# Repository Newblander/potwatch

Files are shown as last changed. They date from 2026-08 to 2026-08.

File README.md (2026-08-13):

# PotWatch

**A clip-on kitchen timer that waits for the water to actually boil.**

*"A watched pot never boils" — so let PotWatch watch it.*

[**potwatch.net**](https://potwatch.net) · Open hardware · Free forever · Not patented, not trademarked

<p align="center">
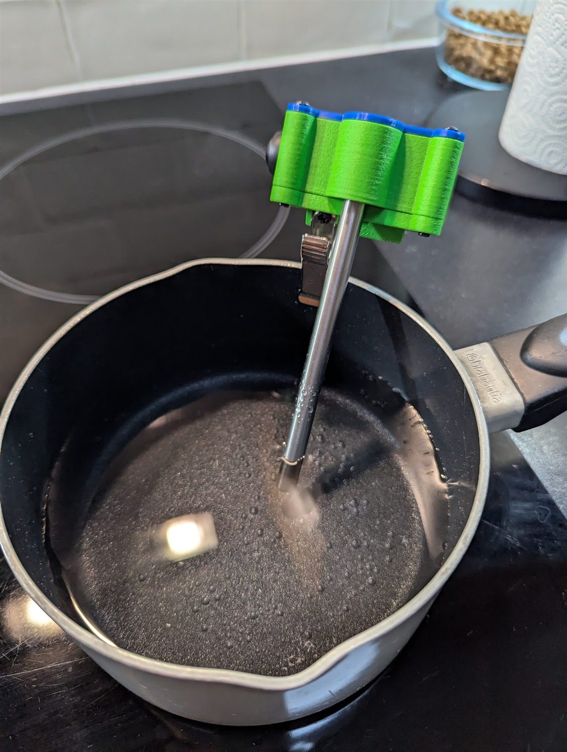
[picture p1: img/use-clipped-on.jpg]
PotWatch clipped to a saucepan with its stainless probe in the water
  
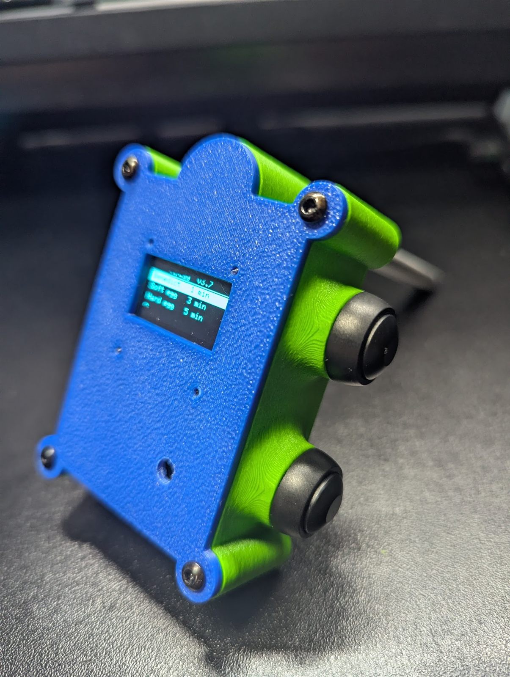
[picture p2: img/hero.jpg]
The PotWatch prototype with its OLED menu lit up
  
</p>

---

Every kitchen timer has the same flaw: it starts counting when you press the button. But "3 minutes for a soft-boiled egg" means three minutes *of boiling*. So you stand at the stove watching for bubbles, guess the moment, and accept that breakfast is a coin flip.

PotWatch hangs on the rim of the pot with a stainless steel probe in the water. It waits until the water reaches the temperature you set, starts the countdown itself, and sounds the alarm when the food is done. Then you can walk away — which is the entire point.

Everything needed to build one is in this repository, and the full documentation is at **[potwatch.net](https://potwatch.net)**.

## It in use

<p align="center">
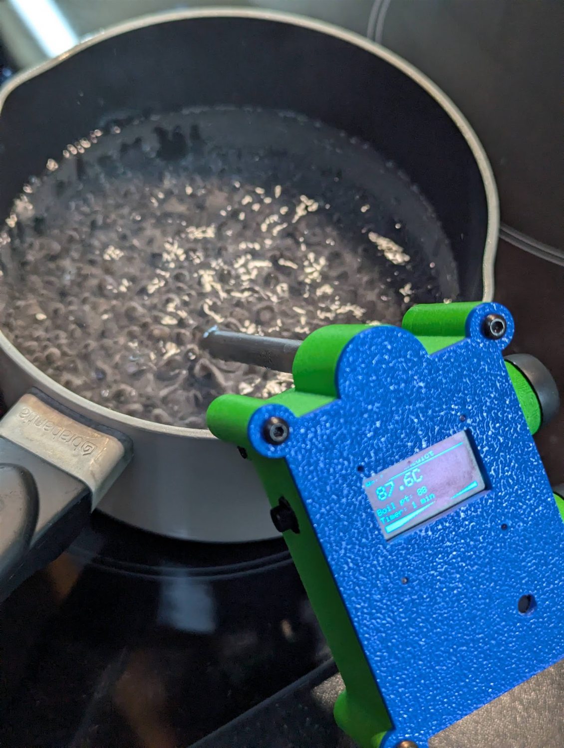
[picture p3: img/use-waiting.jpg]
Screen reading 87.6 C against a trigger of 88
  
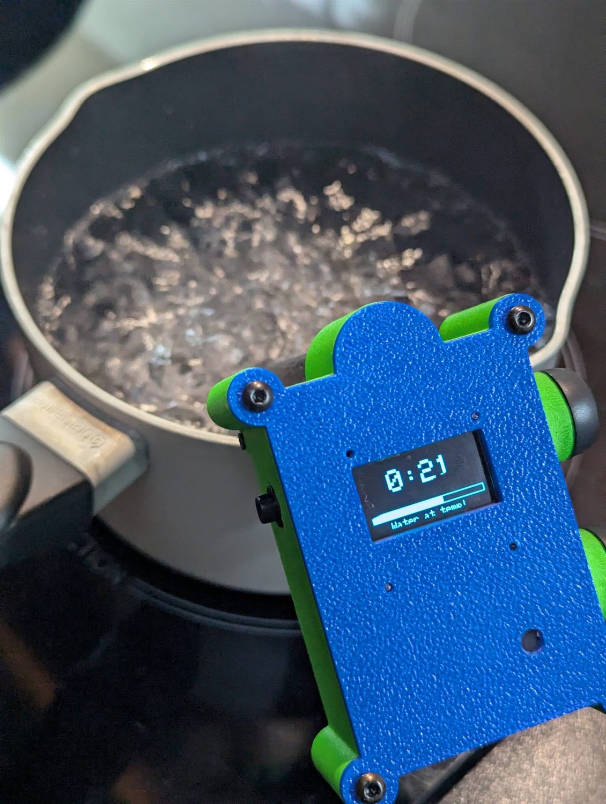
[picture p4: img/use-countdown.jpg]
Counting down from twenty-one seconds, water at temp
  
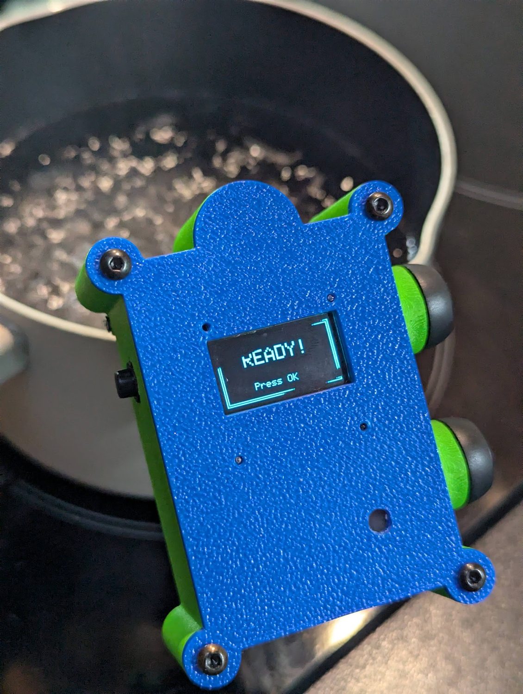
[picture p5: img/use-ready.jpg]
Screen showing READY and Press OK
  
</p>

Left to right: **87.6 °C** against the 88 °C this unit triggers at — the water is working but the countdown has not started. Then the threshold is cleared five times over and the timer runs. Then it shouts.

There is a [12-second clip](video/potwatch-in-use.mp4) of the same thing happening.

## Why the temperature matters

Water does not boil at 100 °C. It boils at whatever the local air pressure dictates — lower at altitude, and drifting by a fraction of a degree as the weather changes. A device that waits for a fixed 100 °C either waits forever or starts early.

PotWatch carries a BMP280 barometer and computes its own threshold:

```
trigger = calibratedTemperature + (currentPressure − calibratedPressure) × 0.03
          clamped to 85…102 °C
```

A one-time calibration pins down the baseline for your kitchen; the barometer handles the daily drift.

**And the threshold does not have to be the boiling point.** What you are really setting is *the temperature at which the countdown starts*. Well before a full boil the water is already working hard — on the author's hob that point is around **88 °C**, which is a fine moment to start timing and turn the heat down. Gentler than a rolling boil, and for most things a better way to cook.

## Features

- **Confirmed detection** — the probe is read every second and five consecutive readings above threshold are required. Steam, splashes and stirring do not trigger it.
- **Pressure compensation** — automatic correction for altitude and weather.
- **Presets** — Benedict (1 min), soft egg (3 min), hard egg (5 min), soup (15 min – 2 h), free-form timer (1 min – 6 h).
- **Dry-pot protection** — if the water boils away and the probe passes 105 °C, the countdown stops and a `NO WATER` alarm sounds.
- **Probe fault detection** — a disconnected or failing sensor shows `CHECK PROBE` rather than inventing a number.
- **Non-blocking alarm** — the buzzer runs from a sequencer, so the buttons stay responsive while it sounds.
- **Self-resetting** — lift the probe out and it silences itself and returns to the menu.
- **Cordless** — LiPo cell, charges over USB-C.

## What is in here

```
├── firmware/potwatch/potwatch.ino   the firmware (Arduino, GPLv3)
├── hardware/
│   ├── wiring-diagram.svg           full schematic, including the power chain
│   └── models/                      the four printed parts, as STL and STEP
├── img/                             photographs
├── video/                           12-second demonstration
├── LICENSE.txt                      GPL v3 — the firmware
└── LICENSE-CC-BY-SA-4.0.txt         CC BY-SA 4.0 — hardware, models, docs
```

## Bill of materials

Roughly **€25** of common hobby parts.

| Part | Notes |
|---|---|
| ESP32-C3 Super Mini | The brain — flashes over USB-C, no programmer needed |
| DS18B20 | Buy the **waterproof probe** version, not the bare chip |
| Stainless steel thermowell | Ready-made, threaded fitting and cable gland; food-grade, cut to length |
| BMP280 barometer | I²C `0x76` — **not** the BME280, which looks identical |
| SSD1306 OLED, 128×64 | I²C `0x3C` |
| Passive piezo buzzer | **Passive**, not active — an active one knows only one note |
| 2 × panel-mount push button | SET and OK — the entire interface |
| 4.7 kΩ resistor | Pull-up for the sensor data line |
| Thermal paste + thin wire | **Do not skip** — see the induction warning below |
| LiPo cell, 3.7 V | 802060 pouch, 1000 mAh on the prototype |
| TP4056 USB-C charger | Get the version **with battery protection** |
| 3.3 V step-down module | Buck converter. A substitute must work from **under 4.2 V** and idle in microamps — **not** LM2596 or MP1584 (both need 4.5 V+), not AMS1117 |
| Self-locking power switch | Breaks the 3.3 V line after the regulator |
| Stainless spring clip | Bought part, screwed between the two printed holders |
| M3 × 6 mm screws ×6, 2 mm self-tappers ×4 | Self-thread into 2.8 mm and 1.8 mm printed holes |

## Wiring

| ESP32-C3 pin | Connects to |
|---|---|
| `GPIO3` | DS18B20 data — needs the 4.7 kΩ pull-up to 3.3 V |
| `GPIO4` | I²C SDA — OLED and BMP280 |
| `GPIO5` | I²C SCL — OLED and BMP280 |
| `GPIO6` | Piezo buzzer, driven directly |
| `GPIO7` | OK button → GND |
| `GPIO10` | SET button → GND |
| `GND` | Also bonded to the stainless thermowell — see below |

Power chain: **cell → TP4056 → 3.3 V step-down → switch → board 3V3 pin.** The board's own USB-C port is for flashing only.

PotWatch wiring diagram

## Printing

| Part | Size | Material on the prototype |
|---|---|---|
| [enclosure](hardware/models/enclosure.stl) · [STEP](hardware/models/enclosure.step) | 60.5 × 84 × 24 mm | Fibre-reinforced ABS |
| [cover](hardware/models/cover.stl) · [STEP](hardware/models/cover.step) | 59 × 84 × 3 mm | ASA |
| [holder1](hardware/models/holder1.stl) · [STEP](hardware/models/holder1.step) | 59 × 15 × 5 mm | Fibre-reinforced ABS |
| [holder2](hardware/models/holder2.stl) · [STEP](hardware/models/holder2.step) | 35 × 15 × 5 mm | Fibre-reinforced ABS |

Every part is published twice: **STL** to print as-is, **STEP** to edit. Bambu Studio, PrusaSlicer and OrcaSlicer import STEP directly, so either one goes straight into the slicer.

Standard slicer settings, no supports needed. **ABS and ASA are chosen deliberately:** the device sits above a pot of steam, and PLA softens around 60 °C. Both want an enclosed printer; on an open-frame machine PETG is the sensible compromise.

The screw holes are printed undersized on purpose so the screws cut their own thread — no nuts and no inserts. Different filaments shrink differently, so test one hole before printing the lot. If you prefer heat-set inserts, open the holes out — that is what the STEP files are for.

## Flashing

1. Install the Arduino IDE and the Espressif ESP32 board package.
2. Install `OneWire`, `DallasTemperature`, `Adafruit GFX`, `Adafruit SSD1306`, `Adafruit BMP280`.
3. Keep `potwatch.ino` in a folder named `potwatch`.
4. Select your ESP32-C3 board. If the serial monitor stays silent, enable **USB CDC On Boot**.
5. Disconnect the battery, connect USB-C and upload.
6. Two beeps means it is alive. Serial at 115200 baud prints live temperatures.

Full instructions: **[potwatch.net/firmware](https://potwatch.net/firmware/)**

## Calibration

Boil a pot, put the probe in, open **Calibrate**, match the right-hand number to the left with SET/OK, hold SET for two seconds. Three beeps confirm it is stored.

Settings live in NVS under the namespace `clipegg` — the project's former name, kept deliberately so calibration survives firmware upgrades.

## ⚠️ If you cook on induction, read this

Early prototypes destroyed DS18B20 sensors one after another. The cause was the hob: a bare semiconductor inside a metal tube next to a large alternating magnetic field. The steel sleeve added to *protect* the sensor was acting as an antenna, feeding the interference straight into it.

Two changes fixed it:

1. **Bed the sensor in thermal paste** (ordinary CPU heatsink compound) before sliding it into the thermowell.
2. **Bond the steel thermowell to GND** with a wire.

The grounded tube becomes a shield rather than an antenna. The paste removes the air gap, which also makes the probe respond noticeably faster.

No failures since, over several months of induction use. That is months of evidence, not years — if you build one and still lose a sensor, please open an issue.

## Known issue — and where help is wanted

**The clip is the weak point.** It holds only when its screws are done up firmly, and the tension slackens with use. Slack enough and the device can tip, lifting the probe out of the liquid — where it will faithfully report that your water is cold and wait forever.

Conveniently, the mount is the most self-contained part of the design: **[`holder1.step`](hardware/models/holder1.step) and [`holder2.step`](hardware/models/holder2.step)** are what carry the spring clip, and nothing else depends on their shape. A better clamp costs you two files, not a rebuild.

If clamping mechanisms are your area, this is the single most valuable contribution the project could receive. Issues and pull requests welcome.

## Licence

- **Firmware** (`firmware/`) — [GNU GPL v3](LICENSE.txt)
- **Hardware, models, diagrams, photographs and documentation** — [CC BY-SA 4.0](LICENSE-CC-BY-SA-4.0.txt)

Nothing here is patented or trademarked, and it never will be.

### How to credit this project

If you publish a remix, a fork, a photo set or a build guide based on the models, diagrams or documentation, copy this line somewhere sensible — a description, a README, a caption:

> PotWatch by Ilia Kuzmin — https://potwatch.net — licensed [CC BY-SA 4.0](https://creativecommons.org/licenses/by-sa/4.0/). Modified from the original.

Drop the last sentence if you did not change anything. That is the whole obligation: **say who made it, link back, note that you changed it, and keep your version under the same licence.**

For the **firmware** the rules are different and a little lighter. GPL v3 does not ask you to advertise anyone. It asks you to keep the copyright notice in the source files, mark what you changed, publish your source under GPL v3 as well, and make that source available to anyone you give a device to. You are free to sell hardware running it.

**What is not covered:** copyright protects these *files*, not the idea. If you look at this thing and design your own from scratch, you owe nothing at all — go ahead, and tell me how it turned out.

---

Made by **Ilia Kuzmin**, 2026 — [3d.ilia.ireland@gmail.com](mailto:3d.ilia.ireland@gmail.com) · [3diy.ie](https://www.3diy.ie/)

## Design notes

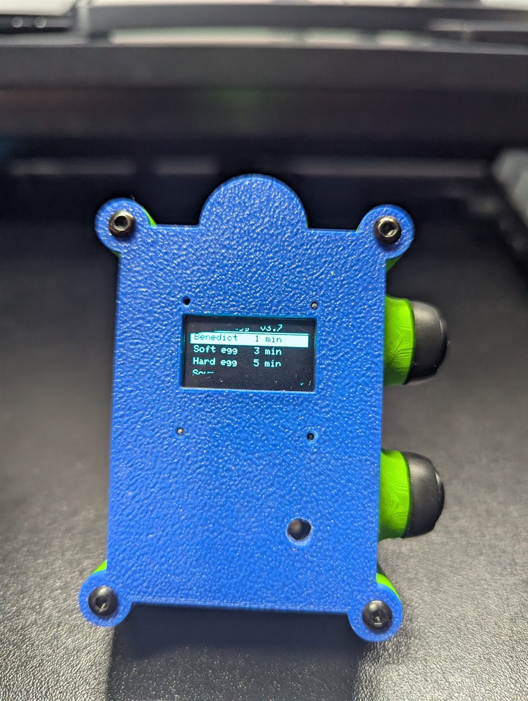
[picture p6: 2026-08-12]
img/menu-front.jpg

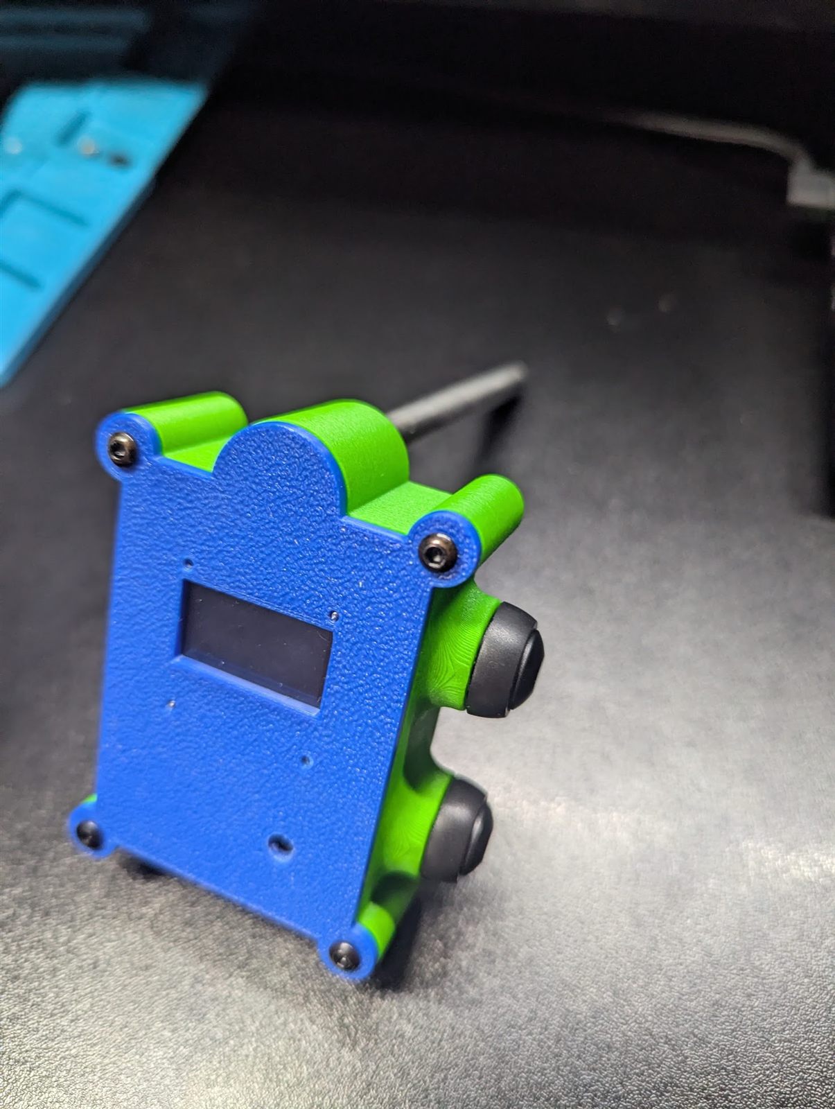
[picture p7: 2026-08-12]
img/device-front.jpg

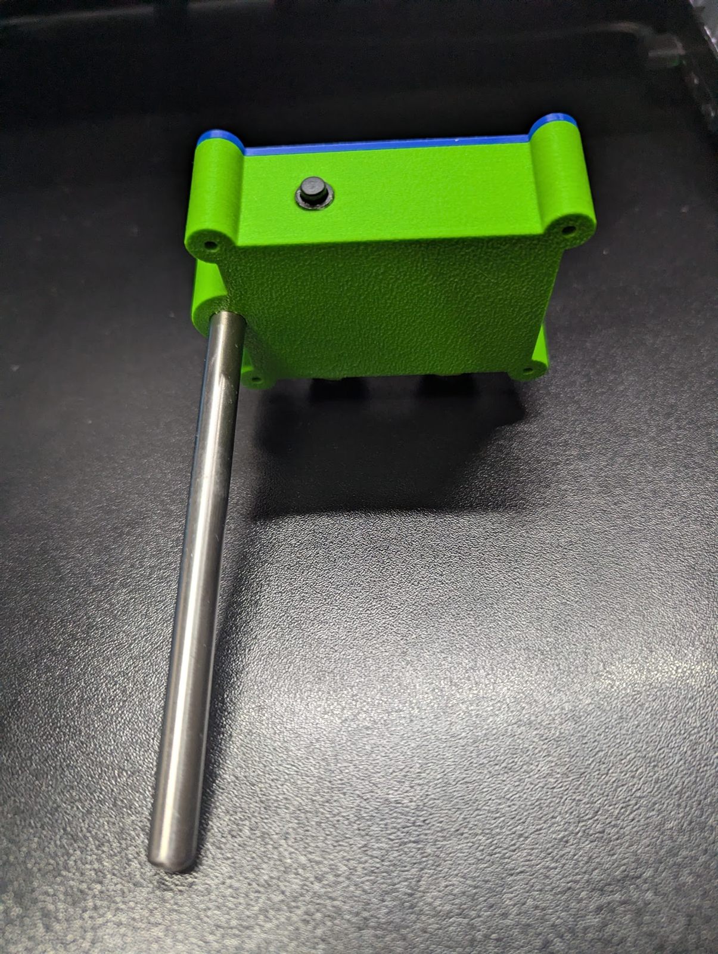
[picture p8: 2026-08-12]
img/probe-back.jpg

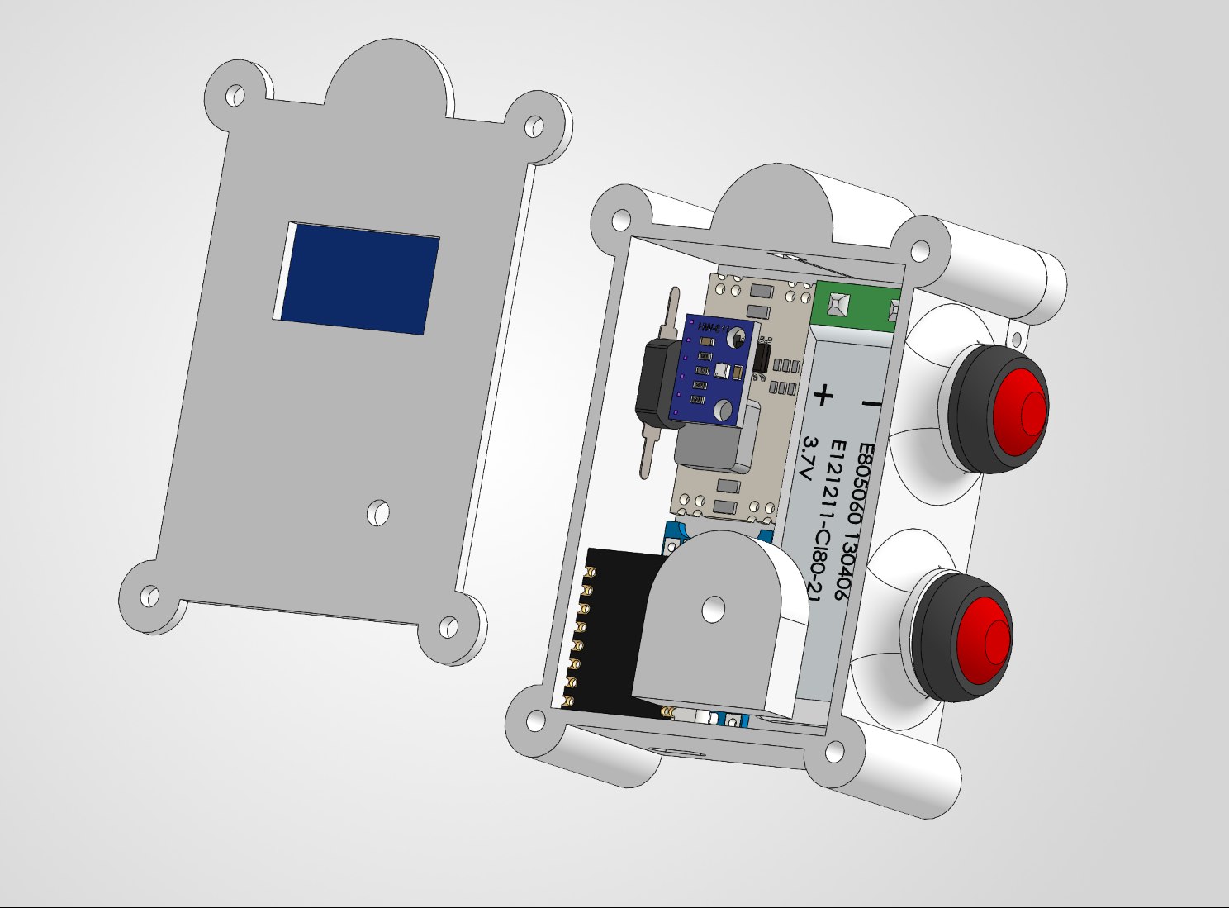
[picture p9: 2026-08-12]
img/exploded-view.jpg

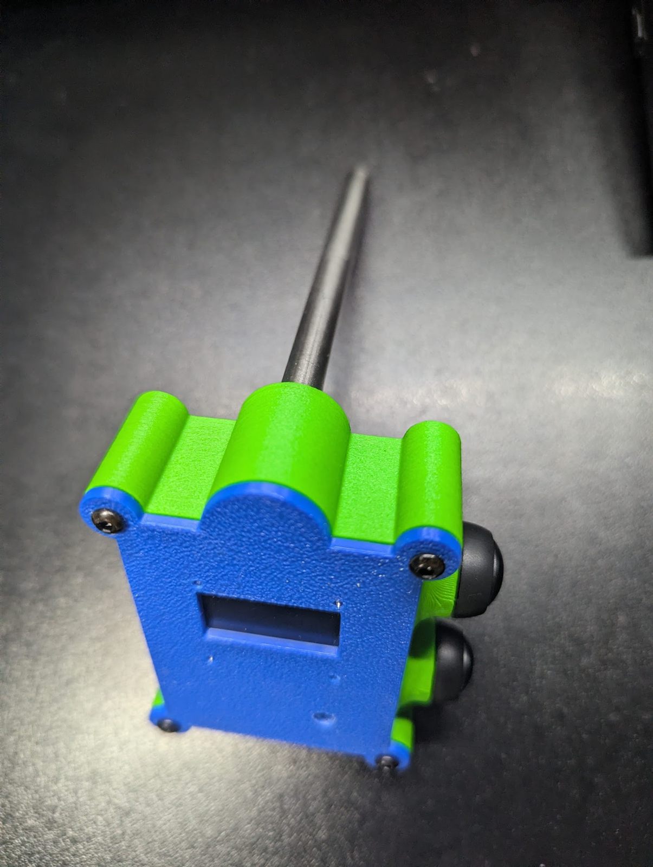
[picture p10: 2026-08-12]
img/top-probe.jpg

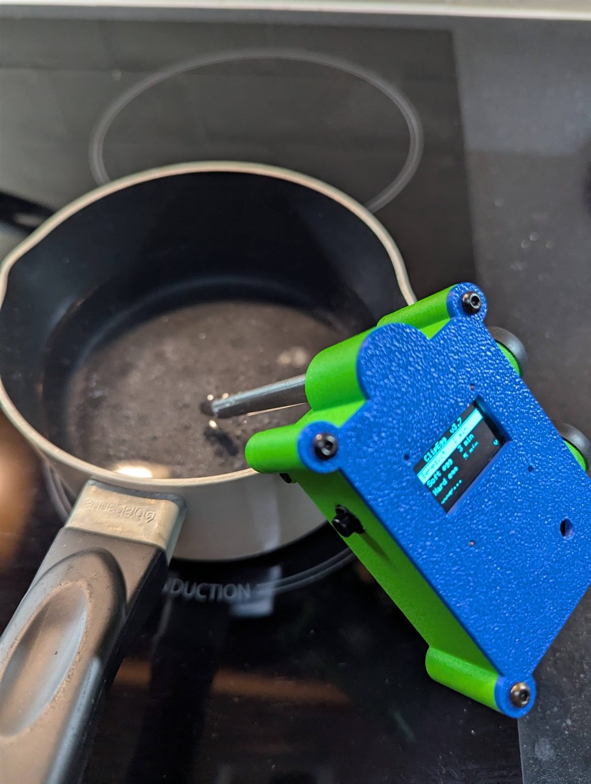
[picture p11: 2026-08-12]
img/use-menu.jpg

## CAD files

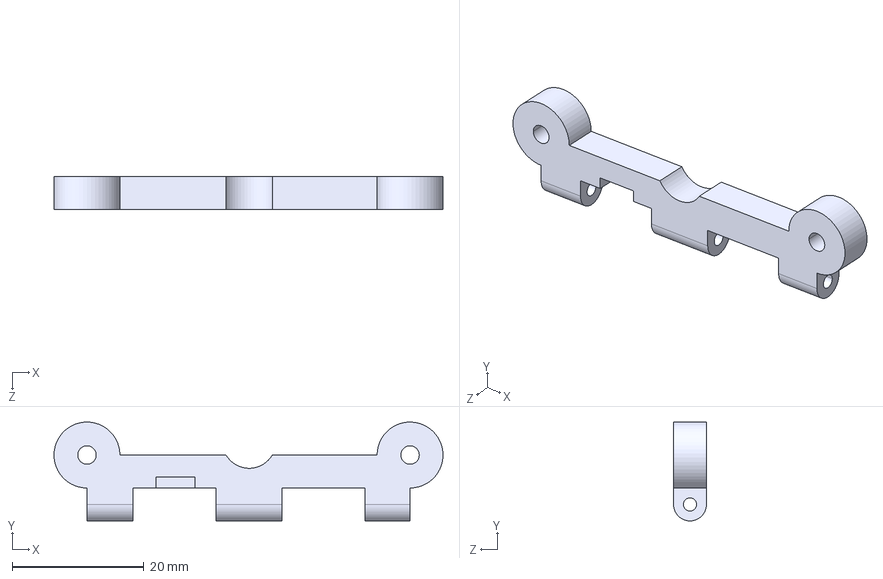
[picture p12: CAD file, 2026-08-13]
hardware/models/holder1.step
59.0 x 15.0 x 5.00 mm

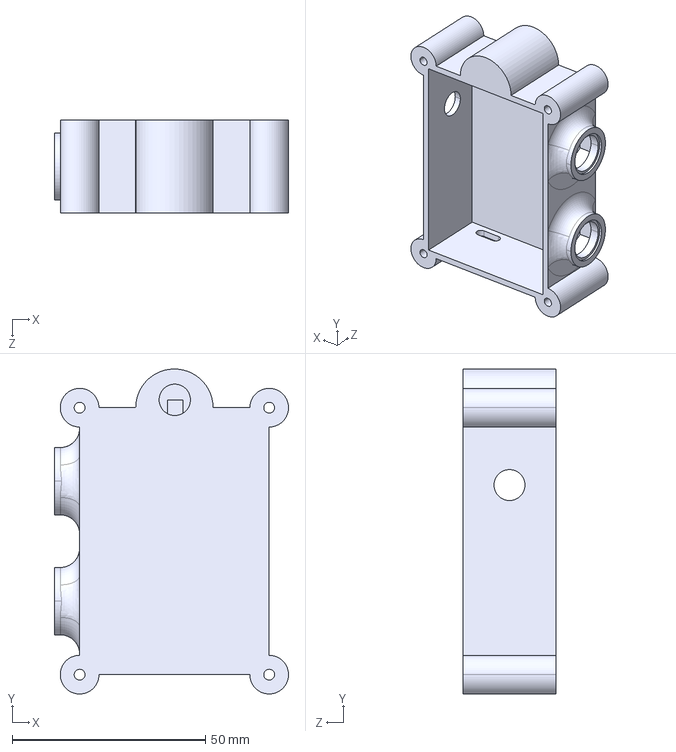
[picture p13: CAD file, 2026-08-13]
hardware/models/enclosure.step
60.5 x 84.0 x 24.0 mm

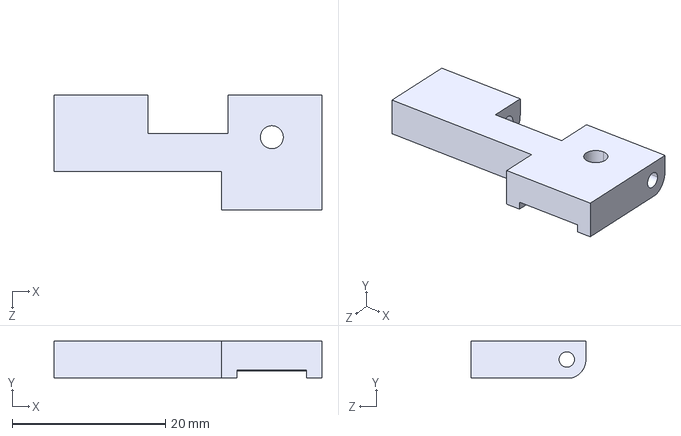
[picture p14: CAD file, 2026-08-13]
hardware/models/holder2.step
35.0 x 4.80 x 15.0 mm

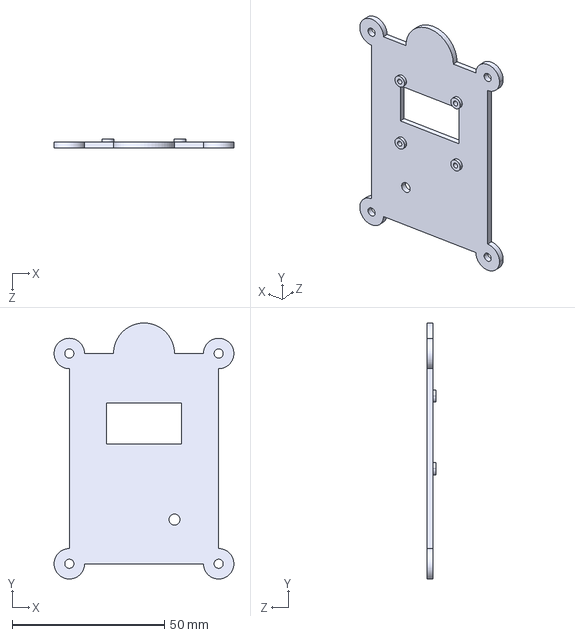
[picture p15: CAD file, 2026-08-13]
hardware/models/cover.step
59.0 x 84.0 x 3.10 mm

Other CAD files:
hardware/models/cover.stl
hardware/models/enclosure.stl
hardware/models/holder1.stl
hardware/models/holder2.stl

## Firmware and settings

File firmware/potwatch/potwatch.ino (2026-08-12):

/**
 * PotWatch v4.0
 * ESP32-C3 Super Mini
 *
 * Clip-on pot thermometer: pick a preset, drop the probe in, walk away.
 * Detects boiling, counts down, alarms when the dish is ready.
 *
 * Project home: https://potwatch.net
 *
 * Copyright (C) 2026 Ilia Kuzmin
 *
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
 * Changelog:
 *   v3.2 Removed Bounce2 -> transparent SimpleButton (reliable on ESP32-C3).
 *   v4.0 Rebrand ClipEgg -> PotWatch. Non-blocking sound engine (device stays
 *        responsive during the alarm). Timer screen: dedicated input handler
 *        with chord window (fixes off-by-one) + hold-both-to-exit. Temperature
 *        polled during COUNTDOWN; optional dry-pot protection + dead-probe
 *        indication. Preset minutes single-sourced from PRESET_MINUTES[].
 *        NVS namespace kept as "clipegg" so saved calibration survives upgrade.
 */

#include <Wire.h>
#include <OneWire.h>
#include <DallasTemperature.h>
#include <Adafruit_GFX.h>
#include <Adafruit_SSD1306.h>
#include <Adafruit_BMP280.h>
#include <Preferences.h>

#define FW_VERSION "v4.0"

#define PIN_DS18B20  3
#define PIN_SDA      4
#define PIN_SCL      5
#define PIN_BUZZER   6
#define PIN_BTN_OK   7
#define PIN_BTN_SET  10

#define OLED_WIDTH   128
#define OLED_HEIGHT  64
#define OLED_ADDR    0x3C
#define BUZZER_FREQ  3000

#define TEMP_POLL_MS       1000
#define DS18B20_CONV_MS     800
#define BOIL_CONFIRM_COUNT    5

#define DEFAULT_BOIL_TEMP   97.6f
#define DEFAULT_BOIL_PRES   1013.25f

// Dry-pot protection: if the probe reads well above boiling for several
// seconds (no water / pot boiled dry) during heat-up or countdown, raise the
// alarm instead of cooking a dead sensor. Set DRY_POT_PROTECT to 0 to disable.
#define DRY_POT_PROTECT       1
#define DRY_POT_TEMP     105.0f
#define DRY_POT_CONFIRM       4
#define SENSOR_DEAD_COUNT     5

#define DEBOUNCE_MS          15
#define HOLD_RESET_MS      3000
#define HOLD_CAL_SAVE_MS   2000
#define HOLD_PHASE1_MS      500
#define HOLD_PHASE2_MS      300
#define HOLD_PHASE3_MS      200
#define HOLD_P2_START      2000
#define HOLD_P3_START      5000

#define CHORD_WINDOW_MS      80   // two presses within this = a chord, not two taps
#define CHORD_EXIT_MS      1500   // hold both buttons this long = exit Timer

#define MENU_BENEDICT  0
#define MENU_SOFT      1
#define MENU_HARD      2
#define MENU_SOUP      3
#define MENU_TIMER     4
#define MENU_CALIBRATE 5
#define MENU_COUNT     6
#define MENU_VISIBLE   4

#define SOUP_MIN   15
#define SOUP_MAX   120
#define SOUP_STEP  15
#define TIMER_MIN  1
#define TIMER_MAX  360

// Alarm reasons (plain ints to avoid Arduino enum-prototype quirks)
#define ALARM_DONE 0
#define ALARM_DRY  1

// ─────────────────────────────────────────────────
// Simple transparent button debouncer — no library
// ─────────────────────────────────────────────────
class SimpleButton {
  uint8_t       _pin;
  bool          _raw;      // last raw digitalRead (true = pressed = LOW pin)
  bool          _state;    // confirmed debounced state
  unsigned long _changeMs; // when raw last changed
  bool          _fell;     // pressed event this update()
  bool          _rose;     // released event this update()
public:
  void begin(uint8_t pin) {
    _pin      = pin;
    pinMode(pin, INPUT_PULLUP);
    _raw      = (digitalRead(pin) == LOW);
    _state    = _raw;
    _changeMs = 0;
    _fell = _rose = false;
  }
  void update(unsigned long now) {
    _fell = _rose = false;
    bool r = (digitalRead(_pin) == LOW);
    if (r != _raw) { _raw = r; _changeMs = now; }   // edge: restart timer
    if (now - _changeMs >= DEBOUNCE_MS && r != _state) {
      _state = r;
      if (_state) _fell = true; else _rose = true;  // confirmed transition
    }
  }
  bool fell()   const { return _fell;  }  // just pressed
  bool rose()   const { return _rose;  }  // just released
  bool isDown() const { return _state; }  // currently held
};

// ─────────────────────────────────────────────────
OneWire           oneWire(PIN_DS18B20);
DallasTemperature tempSensor(&oneWire);
Adafruit_SSD1306  display(OLED_WIDTH, OLED_HEIGHT, &Wire, -1);
Adafruit_BMP280   bmp;
SimpleButton      btnSet, btnOk;
Preferences       prefs;

enum State {
  STATE_MENU, STATE_SOUP_TIME, STATE_CUSTOM_TIME,
  STATE_WAITING_BOIL, STATE_COUNTDOWN, STATE_ALARM, STATE_CALIBRATION
};
State appState = STATE_MENU;

int  menuIndex  = 0;
int  menuScroll = 0;

const char* PRESET_NAMES[MENU_COUNT] = {
  "Benedict", "Soft egg", "Hard egg", "Soup", "Timer", ""
};
// Single source of truth for the fixed egg presets' cook time (minutes).
// 0 = not a fixed-time preset (Soup/Timer/Calibrate handle their own).
const int   PRESET_MINUTES[MENU_COUNT] = { 1, 3, 5, 0, 0, 0 };

// Menu labels: egg rows generated from name + minutes so they can never
// disagree with PRESET_MINUTES; the rest are static.
char        menuLabelBuf[3][20];
const char* MENU_LABELS[MENU_COUNT];

int   activeMinutes   = 3;
int   activePresetIdx = MENU_SOFT;
int   soupMinutes     = 60;
int   timerMinutes    = 5;
float savedBoilBase   = DEFAULT_BOIL_TEMP;
float savedBoilPres   = DEFAULT_BOIL_PRES;
bool  hasBmp          = false;
float calBoilTemp     = DEFAULT_BOIL_TEMP;

float         currentTemp   = 0.0f;
int           boilConfirm   = 0;
int           dryConfirm    = 0;
int           consecutiveBad= 0;
unsigned long convRequestMs = 0;
bool          convPending   = false;
unsigned long countdownEnd  = 0;
int           alarmReason    = ALARM_DONE;

// SET hold state
unsigned long setHoldStart  = 0;
unsigned long setLastRepeat = 0;
bool          setActive     = false;
bool          setHoldFired  = false;

// OK hold state
unsigned long okHoldStart  = 0;
unsigned long okLastRepeat = 0;
bool          okActive     = false;
bool          okHoldFired  = false;

// Timer-screen (STATE_CUSTOM_TIME) dedicated input state
bool          ctSetPend    = false;
bool          ctOkPend     = false;
unsigned long ctSetPendMs  = 0;
unsigned long ctOkPendMs   = 0;
bool          ctChordActive= false;
bool          ctChordFired = false;
unsigned long ctChordStart = 0;

// ─────────────────────────────────────────────────
// Non-blocking sound sequencer (freq 0 = rest)
// ─────────────────────────────────────────────────
#define SEQ_GAP 30
const int* seqFreq   = nullptr;
const int* seqDur    = nullptr;
int        seqLen    = 0;
int        seqIdx    = 0;
unsigned long seqNoteStart = 0;
bool       seqPlaying = false;
bool       seqLoop    = false;

const int CONFIRM_F[] = { BUZZER_FREQ, 0, BUZZER_FREQ, 0, BUZZER_FREQ };
const int CONFIRM_D[] = { 140, 70, 140, 70, 140 };
const int CONFIRM_LEN = 5;

const int ALARM_F[] = { BUZZER_FREQ, 0, BUZZER_FREQ, 0, BUZZER_FREQ, 0 };
const int ALARM_D[] = { 180, 110, 180, 110, 180, 650 };
const int ALARM_LEN = 6;

const int RESET_F[] = { BUZZER_FREQ, 0, BUZZER_FREQ };
const int RESET_D[] = { 200, 80, 200 };
const int RESET_LEN = 3;

void soundStart(const int* f, const int* d, int len, bool loop) {
  seqFreq = f; seqDur = d; seqLen = len;
  seqIdx = 0; seqLoop = loop; seqPlaying = true;
  seqNoteStart = millis();
  if (f[0] > 0) tone(PIN_BUZZER, f[0], d[0]); else noTone(PIN_BUZZER);
}
void soundStop() { seqPlaying = false; noTone(PIN_BUZZER); }
void soundService(unsigned long now) {
  if (!seqPlaying) return;
  if (now - seqNoteStart < (unsigned long)seqDur[seqIdx] + SEQ_GAP) return;
  seqIdx++;
  if (seqIdx >= seqLen) {
    if (seqLoop) seqIdx = 0;
    else { seqPlaying = false; noTone(PIN_BUZZER); return; }
  }
  seqNoteStart = now;
  if (seqFreq[seqIdx] > 0) tone(PIN_BUZZER, seqFreq[seqIdx], seqDur[seqIdx]);
  else                     noTone(PIN_BUZZER);
}
void beepClick() { tone(PIN_BUZZER, BUZZER_FREQ, 25); }

// ─────────────────────────────────────────────────
float currentPressureHpa() {
  return hasBmp ? bmp.readPressure() / 100.0f : DEFAULT_BOIL_PRES;
}
float boilPoint() {
  return constrain(savedBoilBase + (currentPressureHpa() - savedBoilPres) * 0.03f, 85.0f, 102.0f);
}
bool sensorDead() { return consecutiveBad >= SENSOR_DEAD_COUNT; }

void buildMenuLabels() {
  for (int i = 0; i < 3; i++) {
    snprintf(menuLabelBuf[i], sizeof(menuLabelBuf[i]), "%-9s%d min",
             PRESET_NAMES[i], PRESET_MINUTES[i]);
    MENU_LABELS[i] = menuLabelBuf[i];
  }
  MENU_LABELS[MENU_SOUP]      = "Soup...";
  MENU_LABELS[MENU_TIMER]     = "Timer...";
  MENU_LABELS[MENU_CALIBRATE] = "Calibrate";
}

// ─────────────────────────────────────────────────
void setup() {
  Serial.begin(115200);
  delay(200);

  pinMode(PIN_BUZZER, OUTPUT);
  noTone(PIN_BUZZER);

  Wire.begin(PIN_SDA, PIN_SCL);
  Wire.setClock(400000);

  if (!display.begin(SSD1306_SWITCHCAPVCC, OLED_ADDR))
    Serial.println("OLED not found");
  display.clearDisplay();
  display.display();

  hasBmp = bmp.begin(0x76);
  if (!hasBmp) Serial.println("BMP280 not found");

  tempSensor.begin();
  tempSensor.setWaitForConversion(false);
  tempSensor.setResolution(12);
  Serial.printf("DS18B20: %d found\n", tempSensor.getDeviceCount());

  btnSet.begin(PIN_BTN_SET);
  btnOk.begin(PIN_BTN_OK);

  buildMenuLabels();
  loadPrefs();

  tone(PIN_BUZZER, BUZZER_FREQ, 80); delay(150);
  tone(PIN_BUZZER, BUZZER_FREQ, 80);

  Serial.printf("Boot OK PotWatch %s  menu=%d soup=%d timer=%d boilBase=%.1f\n",
                FW_VERSION, menuIndex, soupMinutes, timerMinutes, savedBoilBase);
}

// ─────────────────────────────────────────────────
void loop() {
  unsigned long now = millis();

  btnSet.update(now);
  btnOk.update(now);
  if (appState == STATE_CUSTOM_TIME) {
    handleCustomTime(now);
  } else {
    handleSetButton(now);
    handleOkButton(now);
  }

  pollTemperature(now);
  soundService(now);

  if (appState == STATE_COUNTDOWN && now >= countdownEnd) {
    triggerAlarm(ALARM_DONE);
  }

  // Rate-limited display: buttons polled thousands of times between frames
  static unsigned long lastDraw = 0;
  if (now - lastDraw >= 50) {
    lastDraw = now;
    switch (appState) {
      case STATE_MENU:         drawMenu();         break;
      case STATE_SOUP_TIME:    drawSoupTime();     break;
      case STATE_CUSTOM_TIME:  drawCustomTime();   break;
      case STATE_CALIBRATION:  drawCalibration();  break;
      case STATE_WAITING_BOIL: drawWaitingBoil();  break;
      case STATE_COUNTDOWN:    drawCountdown(now); break;
      case STATE_ALARM:        drawAlarm(now);     break;
    }
  }
}

// ─────────────────────────────────────────────────
// SET BUTTON (all states except STATE_CUSTOM_TIME)
// ─────────────────────────────────────────────────
void handleSetButton(unsigned long now) {

  if (btnSet.fell()) {
    setHoldStart  = now;
    setLastRepeat = now;
    setActive     = true;
    setHoldFired  = false;
    // Calibration steps on release (tap vs hold-to-save); others step now.
    if (appState != STATE_CALIBRATION) onSetStep(1);
  }

  if (btnSet.isDown() && setActive && !setHoldFired) {
    unsigned long held = now - setHoldStart;

    if (appState == STATE_CALIBRATION && held >= HOLD_CAL_SAVE_MS) {
      setHoldFired = true;
      saveCalibration();
      return;
    }

    if (appState == STATE_SOUP_TIME) {
      unsigned long interval; int steps;
      if (held < HOLD_P2_START)      { interval = HOLD_PHASE1_MS; steps = 1; }
      else if (held < HOLD_P3_START) { interval = HOLD_PHASE2_MS; steps = 5; }
      else                           { interval = HOLD_PHASE3_MS; steps = 10; }
      if (now - setLastRepeat >= interval) {
        setLastRepeat = now;
        onSetStep(steps);
      }
    }
  }

  if (btnSet.rose()) {
    if (appState == STATE_CALIBRATION && !setHoldFired) onSetStep(1);
    setActive = false;
  }
}

void onSetStep(int steps) {
  switch (appState) {
    case STATE_MENU:
      menuIndex = (menuIndex + 1) % MENU_COUNT;
      if (menuIndex < menuScroll) menuScroll = menuIndex;
      if (menuIndex >= menuScroll + MENU_VISIBLE) menuScroll = menuIndex - MENU_VISIBLE + 1;
      beepClick();
      break;
    case STATE_SOUP_TIME: {
      int range = SOUP_MAX - SOUP_MIN + SOUP_STEP;
      soupMinutes = SOUP_MIN + ((soupMinutes - SOUP_MIN + SOUP_STEP) % range);
      beepClick();
      break;
    }
    case STATE_CUSTOM_TIME: {
      int range = TIMER_MAX - TIMER_MIN + 1;
      timerMinutes = TIMER_MIN + ((timerMinutes - TIMER_MIN + steps + range * 100) % range);
      beepClick();
      break;
    }
    case STATE_CALIBRATION:
      calBoilTemp = constrain(calBoilTemp + 0.1f, 85.0f, 102.0f);
      beepClick();
      break;
    default: break;
  }
}

// ─────────────────────────────────────────────────
// OK BUTTON (all states except STATE_CUSTOM_TIME)
// short press = action; hold 3s = full reset to menu
// ─────────────────────────────────────────────────
void handleOkButton(unsigned long now) {

  if (btnOk.fell()) {
    okHoldStart  = now;
    okActive     = true;
    okHoldFired  = false;
    beepClick();
    onOkPress();
  }

  if (btnOk.isDown() && okActive && !okHoldFired) {
    if (now - okHoldStart >= HOLD_RESET_MS) {
      okHoldFired = true;
      fullReset();
    }
  }

  if (btnOk.rose()) okActive = false;
}

void onOkPress() {
  switch (appState) {

    case STATE_MENU:
      switch (menuIndex) {
        case MENU_BENEDICT:
        case MENU_SOFT:
        case MENU_HARD:
          activeMinutes   = PRESET_MINUTES[menuIndex];
          activePresetIdx = menuIndex;
          savePrefs();
          startWaitingBoil();
          break;
        case MENU_SOUP:      appState = STATE_SOUP_TIME; break;
        case MENU_TIMER:     enterCustomTime();          break;
        case MENU_CALIBRATE: calBoilTemp = boilPoint(); appState = STATE_CALIBRATION; break;
      }
      break;

    case STATE_SOUP_TIME:
      activeMinutes = soupMinutes; activePresetIdx = MENU_SOUP;
      savePrefs(); startWaitingBoil();
      break;

    case STATE_WAITING_BOIL:
      soundStop();
      appState = STATE_MENU;
      Serial.println("WAITING_BOIL cancelled -> MENU");
      break;

    case STATE_COUNTDOWN:
      soundStop();
      appState = STATE_MENU;
      Serial.println("COUNTDOWN cancelled -> MENU");
      break;

    case STATE_CALIBRATION:
      calBoilTemp = constrain(calBoilTemp - 0.1f, 85.0f, 102.0f);
      break;

    case STATE_ALARM:
      soundStop();
      alarmReason = ALARM_DONE;
      loadPrefs();
      appState = STATE_MENU;
      break;

    default: break;
  }
}

// ─────────────────────────────────────────────────
// TIMER SCREEN input — dedicated handler
//   SET  tap = +1 min,  hold = accelerating +
//   OK   tap = -1 min,  hold = accelerating -
//   both tapped together   = start
//   both held >1.5s        = exit to menu
// The chord window defers a single-button step long enough to tell a
// deliberate chord from a lone tap, so START no longer lands off-by-one.
// ─────────────────────────────────────────────────
void enterCustomTime() {
  appState      = STATE_CUSTOM_TIME;
  setActive     = okActive = false;
  ctSetPend     = ctOkPend = false;
  ctChordActive = ctChordFired = false;
}

void handleCustomTime(unsigned long now) {
  bool s = btnSet.isDown();
  bool o = btnOk.isDown();

  // ---------- both down = chord ----------
  if (s && o) {
    ctSetPend = ctOkPend = false;              // it's a chord, not two taps
    if (!ctChordActive) { ctChordActive = true; ctChordFired = false; ctChordStart = now; }
    if (!ctChordFired && now - ctChordStart >= CHORD_EXIT_MS) {
      ctChordFired = true;                     // long chord -> exit
      setActive = okActive = false;
      appState  = STATE_MENU;
      beepClick();
      Serial.println("CUSTOM_TIME exit -> MENU");
    }
    return;
  }

  // ---------- chord released ----------
  if (ctChordActive) {
    ctChordActive = false;
    setActive = okActive = false;
    if (!ctChordFired) {                        // short chord -> start
      activeMinutes = timerMinutes; activePresetIdx = MENU_TIMER;
      savePrefs(); startWaitingBoil();
    }
    return;
  }

  // ---------- SET alone: +1 tap / accelerating hold ----------
  if (btnSet.fell()) { ctSetPend = true; ctSetPendMs = now; }
  if (ctSetPend && now - ctSetPendMs >= CHORD_WINDOW_MS) {   // survived window -> real press
    ctSetPend = false;
    setActive = true; setHoldStart = ctSetPendMs; setLastRepeat = now;
    onSetStep(1);
  }
  if (s && setActive) {
    unsigned long held = now - setHoldStart;
    unsigned long interval; int steps;
    if (held < HOLD_P2_START)      { interval = HOLD_PHASE1_MS; steps = 1; }
    else if (held < HOLD_P3_START) { interval = HOLD_PHASE2_MS; steps = 5; }
    else                           { interval = HOLD_PHASE3_MS; steps = 10; }
    if (now - setLastRepeat >= interval) { setLastRepeat = now; onSetStep(steps); }
  }
  if (btnSet.rose()) {
    if (ctSetPend) { ctSetPend = false; onSetStep(1); }   // quick tap shorter than window
    setActive = false;
  }

  // ---------- OK alone: -1 tap / accelerating hold ----------
  if (btnOk.fell()) { ctOkPend = true; ctOkPendMs = now; }
  if (ctOkPend && now - ctOkPendMs >= CHORD_WINDOW_MS) {
    ctOkPend = false;
    okActive = true; okHoldStart = ctOkPendMs; okLastRepeat = now;
    onSetStep(-1);
  }
  if (o && okActive) {
    unsigned long held = now - okHoldStart;
    unsigned long interval; int steps;
    if (held < HOLD_P2_START)      { interval = HOLD_PHASE1_MS; steps = 1; }
    else if (held < HOLD_P3_START) { interval = HOLD_PHASE2_MS; steps = 5; }
    else                           { interval = HOLD_PHASE3_MS; steps = 10; }
    if (now - okLastRepeat >= interval) { okLastRepeat = now; onSetStep(-steps); }
  }
  if (btnOk.rose()) {
    if (ctOkPend) { ctOkPend = false; onSetStep(-1); }
    okActive = false;
  }
}

// ─────────────────────────────────────────────────
void startWaitingBoil() {
  boilConfirm    = 0;
  dryConfirm     = 0;
  consecutiveBad = 0;
  convPending    = false;
  convRequestMs  = 0;          // trigger first DS18B20 read immediately
  appState       = STATE_WAITING_BOIL;
  tone(PIN_BUZZER, BUZZER_FREQ, 60);
  Serial.printf("-> WAITING_BOIL  %s  %d min  boilPt=%.2fC\n",
                PRESET_NAMES[activePresetIdx], activeMinutes, boilPoint());
}

void startCountdown() {
  appState     = STATE_COUNTDOWN;
  countdownEnd = millis() + (unsigned long)activeMinutes * 60UL * 1000UL;
  dryConfirm   = 0;
  soundStart(CONFIRM_F, CONFIRM_D, CONFIRM_LEN, false);
  Serial.println("Boil confirmed -> COUNTDOWN");
}

void triggerAlarm(int reason) {
  alarmReason = reason;
  appState    = STATE_ALARM;
  soundStart(ALARM_F, ALARM_D, ALARM_LEN, true);
  Serial.printf("-> ALARM (%s)\n", reason == ALARM_DRY ? "DRY POT" : "READY");
}

void saveCalibration() {
  savedBoilBase = calBoilTemp;
  savedBoilPres = currentPressureHpa();
  prefs.begin("clipegg", false);
  prefs.putFloat("boil_base", savedBoilBase);
  prefs.putFloat("boil_pres", savedBoilPres);
  prefs.end();
  appState = STATE_MENU;
  soundStart(CONFIRM_F, CONFIRM_D, CONFIRM_LEN, false);
  Serial.printf("Calibration saved: %.1fC @ %.1f hPa\n", savedBoilBase, savedBoilPres);
}

void fullReset() {
  soundStop();
  setActive = false;
  okActive  = false;
  loadPrefs();
  appState  = STATE_MENU;
  soundStart(RESET_F, RESET_D, RESET_LEN, false);
  Serial.println("Full reset -> MENU");
}

// ─────────────────────────────────────────────────
// TEMPERATURE — async, polled whenever the reading matters
// ─────────────────────────────────────────────────
void pollTemperature(unsigned long now) {
  bool needsTemp = (appState == STATE_WAITING_BOIL ||
                    appState == STATE_CALIBRATION   ||
                    appState == STATE_COUNTDOWN     ||
                    appState == STATE_ALARM);
  if (!needsTemp) {
    convPending   = false;
    convRequestMs = now - TEMP_POLL_MS;
    return;
  }

  if (!convPending && now - convRequestMs >= TEMP_POLL_MS) {
    tempSensor.requestTemperatures();
    convRequestMs = now;
    convPending   = true;
    return;
  }
  if (!convPending || now - convRequestMs < DS18B20_CONV_MS) return;

  convPending = false;
  float t = tempSensor.getTempCByIndex(0);

  // Classify the reading. 85.0 is the DS18B20 power-on reset value; -127 is
  // "disconnected"; both are garbage. A sustained 105-150C is a plausible
  // real reading meaning the water is gone, not noise.
  bool garbage = (t == DEVICE_DISCONNECTED_C || t == 85.0f || t < -10.0f || t > 150.0f);

  if (garbage) {
    if (consecutiveBad < 1000) consecutiveBad++;
    Serial.printf("DS18B20 bad: %.2f (badN=%d)\n", t, consecutiveBad);
    return;                       // keep last good currentTemp on screen
  }
  consecutiveBad = 0;
  currentTemp = t;

#if DRY_POT_PROTECT
  if (appState == STATE_WAITING_BOIL || appState == STATE_COUNTDOWN) {
    if (currentTemp >= DRY_POT_TEMP) {
      if (++dryConfirm >= DRY_POT_CONFIRM) {
        Serial.println("DRY POT detected");
        triggerAlarm(ALARM_DRY);
        return;
      }
    } else {
      dryConfirm = 0;
    }
  }
#endif

  float threshold = boilPoint() - 0.3f;
  Serial.printf("T=%.2f  boilPt=%.2f  thr=%.2f  confirm=%d\n",
                currentTemp, boilPoint(), threshold, boilConfirm);

  if (appState == STATE_WAITING_BOIL) {
    if (currentTemp >= threshold) {
      if (++boilConfirm >= BOIL_CONFIRM_COUNT) startCountdown();
    } else {
      boilConfirm = 0;
    }
  }

  // After the ready signal, pulling the probe out (temp drops) returns to menu.
  if (appState == STATE_ALARM && currentTemp < (boilPoint() - 5.0f)) {
    soundStop();
    alarmReason = ALARM_DONE;
    loadPrefs();
    appState = STATE_MENU;
    Serial.println("Probe removed -> MENU");
  }
}
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

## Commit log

2026-08-12 PotWatch: open hardware clip-on pot timer
    A kitchen timer that waits for the water to reach a set temperature before
    starting the countdown, rather than counting from the moment you press a
    button. ESP32-C3, DS18B20 probe in a grounded stainless thermowell, BMP280
    for pressure compensation, 3D-printed clip-on body.
    Firmware GPLv3, hardware and documentation CC BY-SA 4.0. Nothing patented.
    Full documentation at potwatch.net.
    [cover.step, enclosure.step, holder1.step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]
2026-08-13 Add STL exports and refresh the STEP files
    Every printed part is now published in both formats: STL to print as-is,
    STEP to edit. The STEP files are re-exported from the current CAD. The
    printing table gains per-part links and bounding-box sizes.
    [cover.step, cover.stl, enclosure.step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]
2026-08-18 Add a PNG of the wiring diagram, and correct the cell label
    The power block was titled "Li-ion cell" while its own subtitle said LiPo
    802060. LiPo is correct. The PNG is for places that will not preview an SVG.

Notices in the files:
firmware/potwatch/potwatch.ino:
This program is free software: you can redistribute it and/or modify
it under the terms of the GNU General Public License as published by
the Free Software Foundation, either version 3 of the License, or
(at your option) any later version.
